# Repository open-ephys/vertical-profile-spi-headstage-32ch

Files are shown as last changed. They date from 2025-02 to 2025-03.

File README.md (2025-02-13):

# vertical-profile-spi-headstage-32ch
Design files of a 32 channels headstage.

## Licensing

The designs, documentation, and photos available in this repository are free: you can redistribute it and/or modify it under the terms of the used license.
Check the file named LICENSE.

<br />This work is licensed under a <a rel="license" href="http://creativecommons.org/licenses/by-nc-sa/3.0/igo/">Creative Commons Attribution-NonCommercial-ShareAlike 3.0 IGO License</a>.

[1]: https://docs.google.com/spreadsheets/d/1aobmmEzBDethzIlrm1eg0eYkBqlyX3s9WbA9KgRwVQI/edit?usp=sharing

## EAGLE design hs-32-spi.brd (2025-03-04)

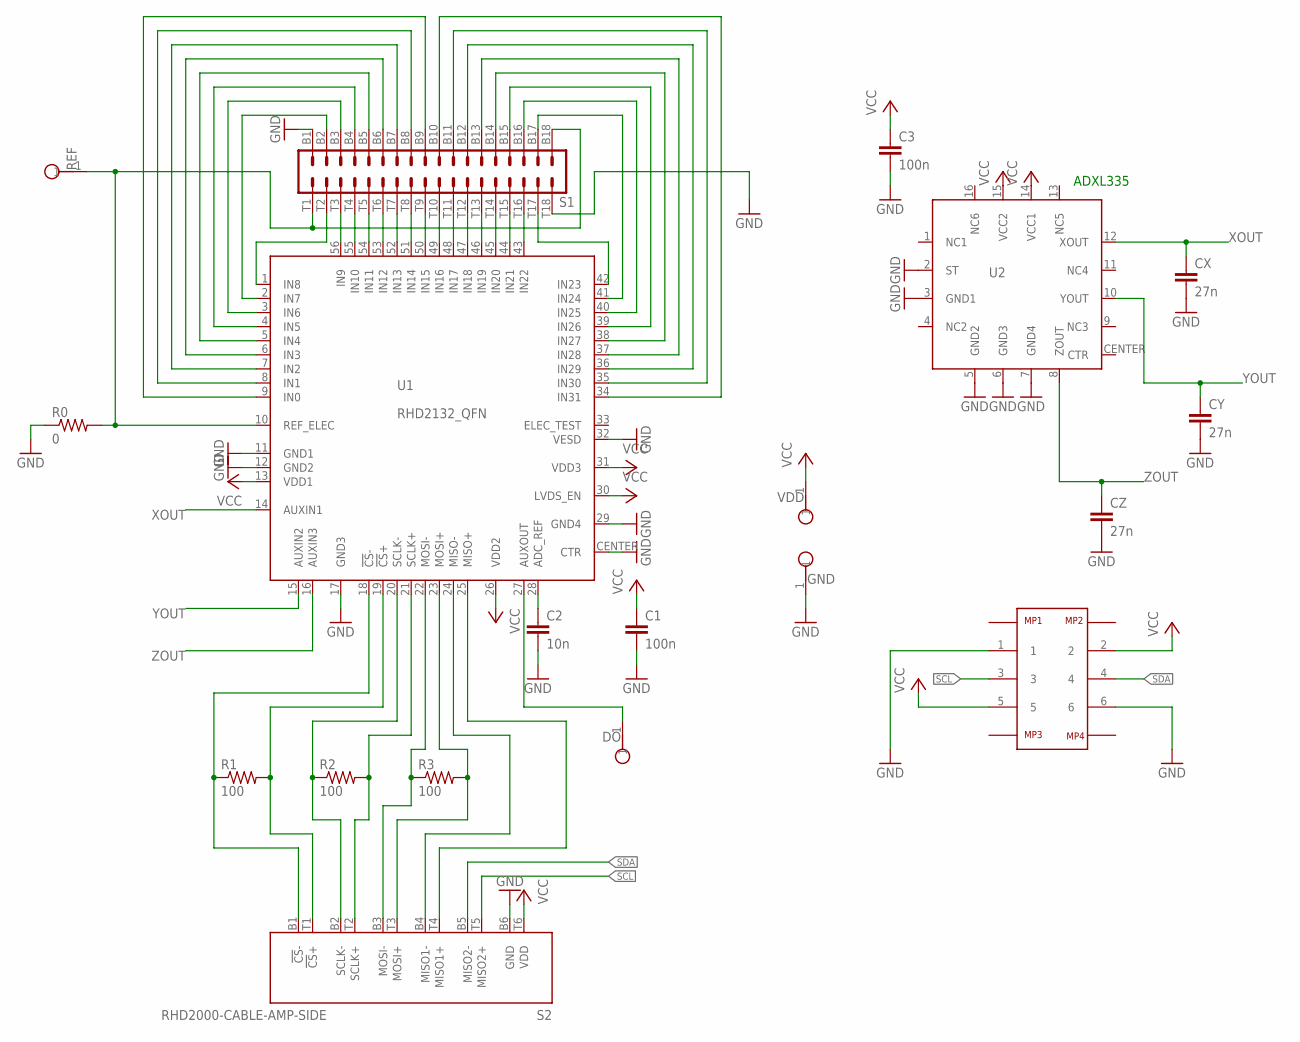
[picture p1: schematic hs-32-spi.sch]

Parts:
C1, C3: 100n; 0402
C2: 10n; 0402
CX: 27n; 0402
CY: 27n; 0402
CZ: 27n; 0402
DO: TESTPOINT_SMALL
GND: TESTPOINT_SMALL
R0: 0; 0402
R1, R2, R3: 100; 0201
REF: TESTPOINT_SMALL
S1: OMNETICS_A79025
S2: RHD2000-CABLE-AMP-SIDE; OMNETICS_PZN-12-AA
U1: RHD2132_QFN; QFN56_8_X_8_LARGE
U2: ADXL335
U3: MOLEX_5050700622
VDD: TESTPOINT_SMALL

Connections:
GND: C1.2, C2.2, C3.2, CX.2, CY.2, CZ.2, GND.1, R0.1, S1.B1, S1.T18, S2.B6 (GND), U1.11 (GND1), U1.12 (GND2), U1.17 (GND3), U1.29 (GND4), U1.32 (VESD), U1.CENTER (CTR), U2.2 (ST), U2.3 (GND1), U2.5 (GND2), U2.6 (GND3), U2.7 (GND4), U3.1, U3.6
unnamed: R0.2, REF.1, S1.B18, S1.T1, U1.10 (REF_ELEC)
unnamed: S1.B3, U1.3 (IN6)
unnamed: S1.B2, U1.2 (IN7)
unnamed: S1.B4, U1.4 (IN5)
unnamed: S1.B5, U1.5 (IN4)
unnamed: S1.B6, U1.6 (IN3)
unnamed: S1.B7, U1.7 (IN2)
unnamed: S1.B8, U1.8 (IN1)
unnamed: S1.B9, U1.9 (IN0)
unnamed: S1.B10, U1.34 (IN31)
unnamed: R1.1, S2.B1 (!CS!-), U1.18 (!CS!-)
unnamed: S1.B17, U1.41 (IN24)
unnamed: S1.B16, U1.40 (IN25)
unnamed: S1.B15, U1.39 (IN26)
unnamed: S1.B14, U1.38 (IN27)
unnamed: S1.B13, U1.37 (IN28)
unnamed: S1.B12, U1.36 (IN29)
unnamed: S1.B11, U1.35 (IN30)
unnamed: S1.T9, U1.50 (IN15)
unnamed: S1.T8, U1.51 (IN14)
unnamed: S1.T7, U1.52 (IN13)
unnamed: S1.T3, U1.56 (IN9)
unnamed: S1.T4, U1.55 (IN10)
unnamed: S1.T5, U1.54 (IN11)
unnamed: S1.T6, U1.53 (IN12)
unnamed: S1.T10, U1.49 (IN16)
unnamed: S1.T11, U1.48 (IN17)
unnamed: S1.T12, U1.47 (IN18)
unnamed: S1.T13, U1.46 (IN19)
unnamed: S1.T14, U1.45 (IN20)
unnamed: S1.T15, U1.44 (IN21)
unnamed: S1.T16, U1.43 (IN22)
unnamed: S1.T2, U1.1 (IN8)
unnamed: S1.T17, U1.42 (IN23)
unnamed: R1.2, S2.T1 (!CS!+), U1.19 (!CS!+)
unnamed: R2.1, S2.B2 (SCLK-), U1.20 (SCLK-)
unnamed: R2.2, S2.T2 (SCLK+), U1.21 (SCLK+)
unnamed: R3.1, S2.B3 (MOSI-), U1.22 (MOSI-)
unnamed: R3.2, S2.T3 (MOSI+), U1.23 (MOSI+)
unnamed: S2.B4 (MISO1-), U1.24 (MISO-)
unnamed: S2.T4 (MISO1+), U1.25 (MISO+)
unnamed: C2.1, U1.28 (ADC_REF)
unnamed: DO.1, U1.27 (AUXOUT)
SCL: S2.T5 (MISO2+), U3.3
SDA: S2.B5 (MISO2-), U3.4
VCC: C1.1, C3.1, S2.T6 (VDD), U1.13 (VDD1), U1.26 (VDD2), U1.30 (LVDS_EN), U1.31 (VDD3), U2.14 (VCC1), U2.15 (VCC2), U3.2, U3.5, VDD.1
XOUT: CX.1, U1.14 (AUXIN1), U2.12 (XOUT)
YOUT: CY.1, U1.15 (AUXIN2), U2.10 (YOUT)
ZOUT: CZ.1, U1.16 (AUXIN3), U2.8 (ZOUT)

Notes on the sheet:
ADXL335

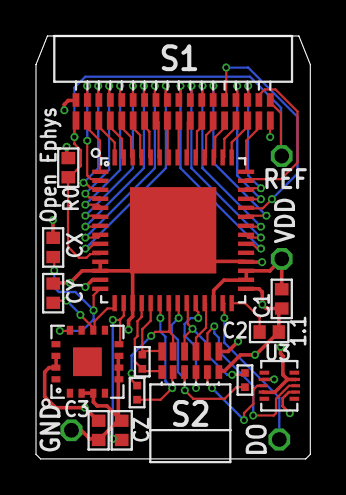
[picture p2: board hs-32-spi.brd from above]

Board: 4 copper layers, 15.2 x 23.5 mm, 20 parts (1 on the bottom side), 50 nets.

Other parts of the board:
X: OE-LOGO_3.5X2.5; OE-LOGO-3.5X2.5

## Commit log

2025-02-13 Added design files.
    [hs-32-spi.brd, hs-32-spi.sch]
2025-02-13 Added initial attempt of adding an expansion connector.
    [hs-32-spi.brd, hs-32-spi.sch]
2025-03-03 Changed location of Omnetics connector closer to headstage center.
    . This allowed space to move the new expansion connector to a position where there's no need to increase the headstage size.
    TO DO
    . Complete the layout.
    [hs-32-spi.brd]
2025-03-04 Finished layout for v1.1
    [hs-32-spi.brd, hs-32-spi.sch]
